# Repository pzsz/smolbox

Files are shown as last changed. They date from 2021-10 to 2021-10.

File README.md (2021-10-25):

# Smolbox thumb & pinky

[Bill of Materials](docs/BOM.md)

[Preparing Brooks board & Soldering tips](docs/brooks_prepare.md)

The Smolbox, a portable arcade controller.

* Based on the Brook Fighting Board 
* Wireless Brook Board version compatible with 
PS3&4, PC, Switch (https://www.brookaccessory.com/detail/41130595/). 
* Zero-Pi Brook Board compatible with 
PS3&2, PC, Switch (no PS4 comparability) (https://www.brookaccessory.com/detail/53169470).
* USB-C port.
* Uses hot-swapable low profile Kailh Choc Red Switches (only Choc switches can be used, full-sized switches will not work).
* Bottom plate made from 1mm brushed stainless steel or 3mm acrylic.

## Thumb version
Ultra portable fighting games controller utilising thumb finger for the jump button.
* Sized 181mm x 73mm and 17mm high (without rubber feet (1mm) and keys). Body made from 3mm acrylic.

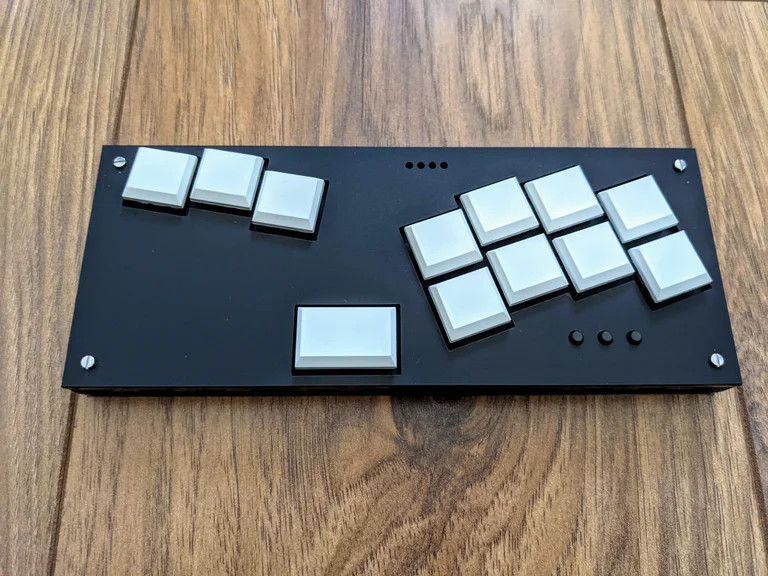
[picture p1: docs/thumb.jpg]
Smolbox Thumb


## Pinky version
Ultra portable fighting games controller utilising pinky finger for the second jump button.
* Sized 181mm x 61mm and 17mm high (without rubber feet (1mm) and keys). Body made from 3mm acrylic.

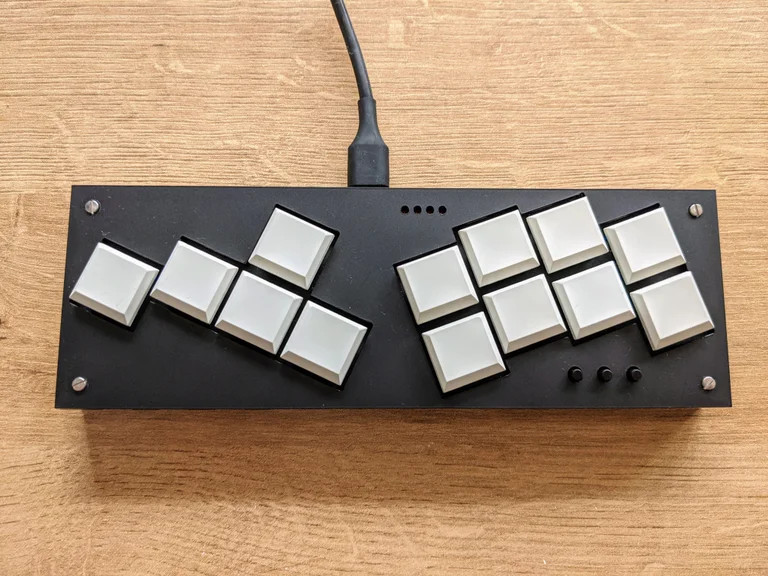
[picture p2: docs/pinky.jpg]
Smolbox Pinky


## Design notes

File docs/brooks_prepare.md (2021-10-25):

# Brooks board prepaeation

Let's prepare the Brooks Board. We have to get from here:

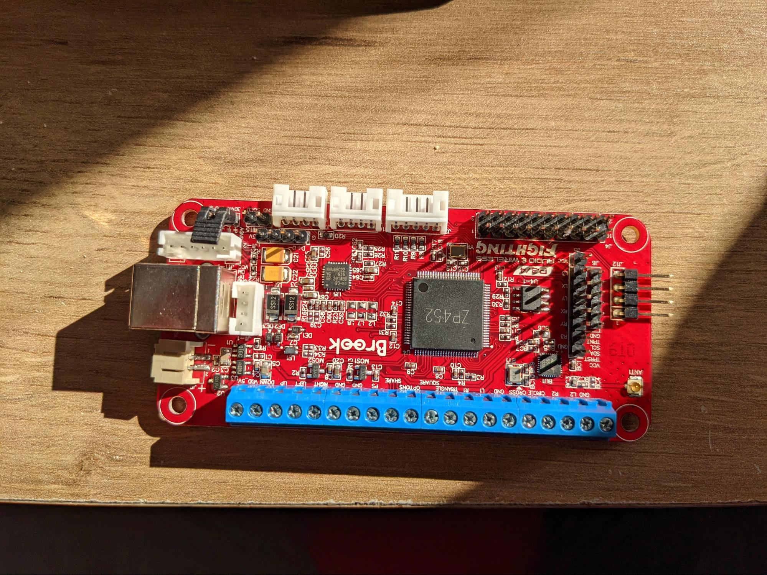
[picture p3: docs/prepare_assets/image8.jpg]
Brooks board


To this:
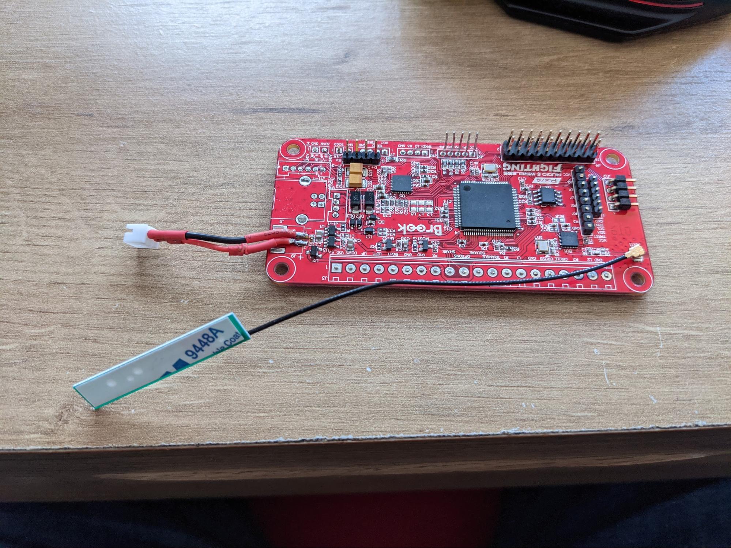
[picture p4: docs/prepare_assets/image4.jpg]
No headers


Items to be modified:
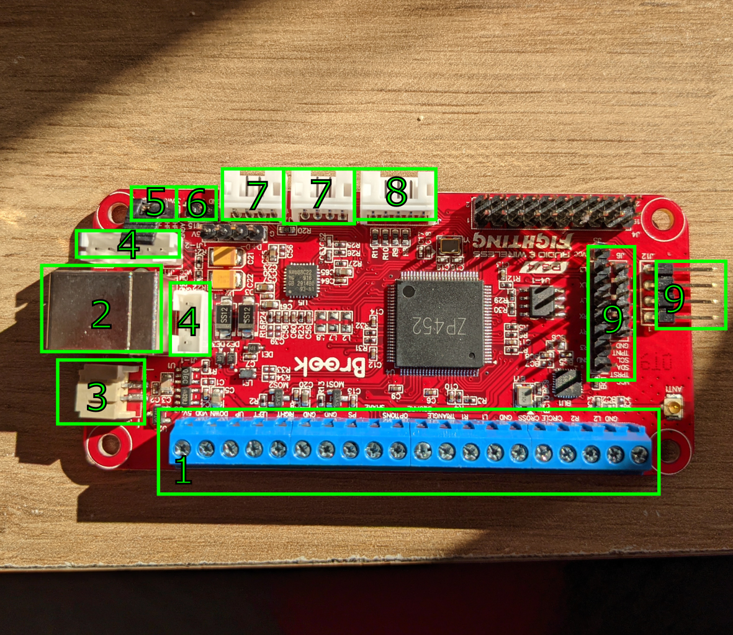
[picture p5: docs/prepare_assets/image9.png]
List of parts to be changed


1.This needs to be removed by grabbing in pliers and rocking them back and forth. Remaining pins need to be trimmed with a cutter

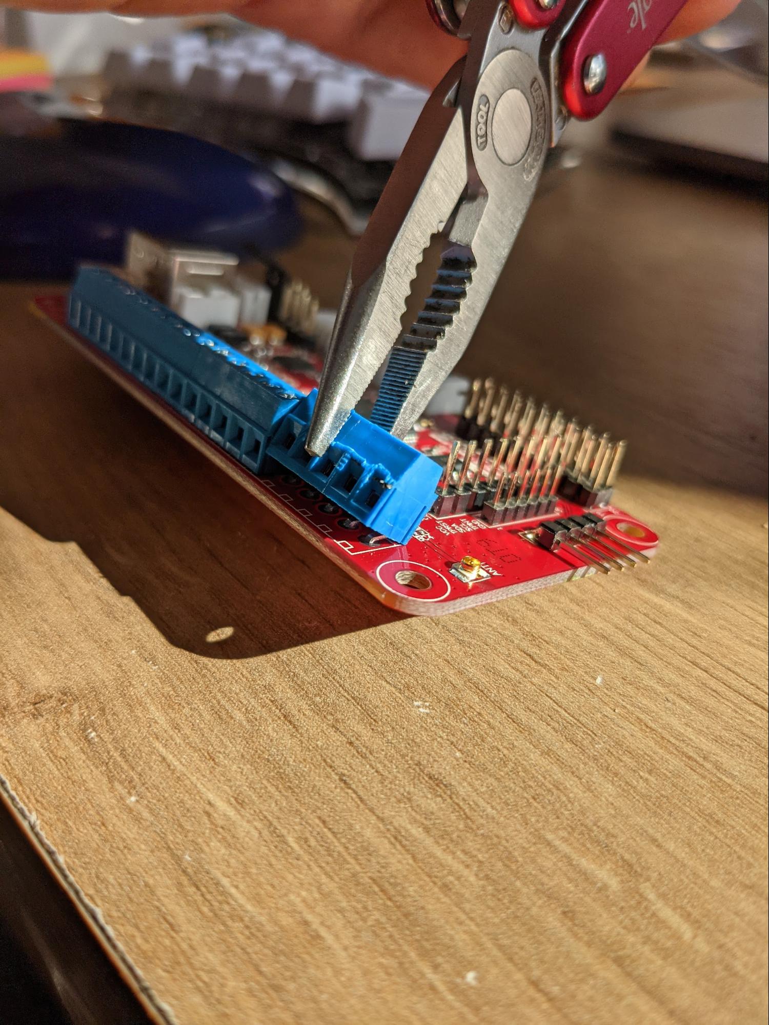
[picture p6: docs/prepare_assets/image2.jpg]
Removed usb port


2. This is the difficult one. You need to cut this into small pieces with a cutter. Be wary that this may dull your cutter if it’s too small. USB is anchored into pcb on its sides and by 4 USB pins. When you remove the side anchors, it comes off easily by rocking it back and forth.

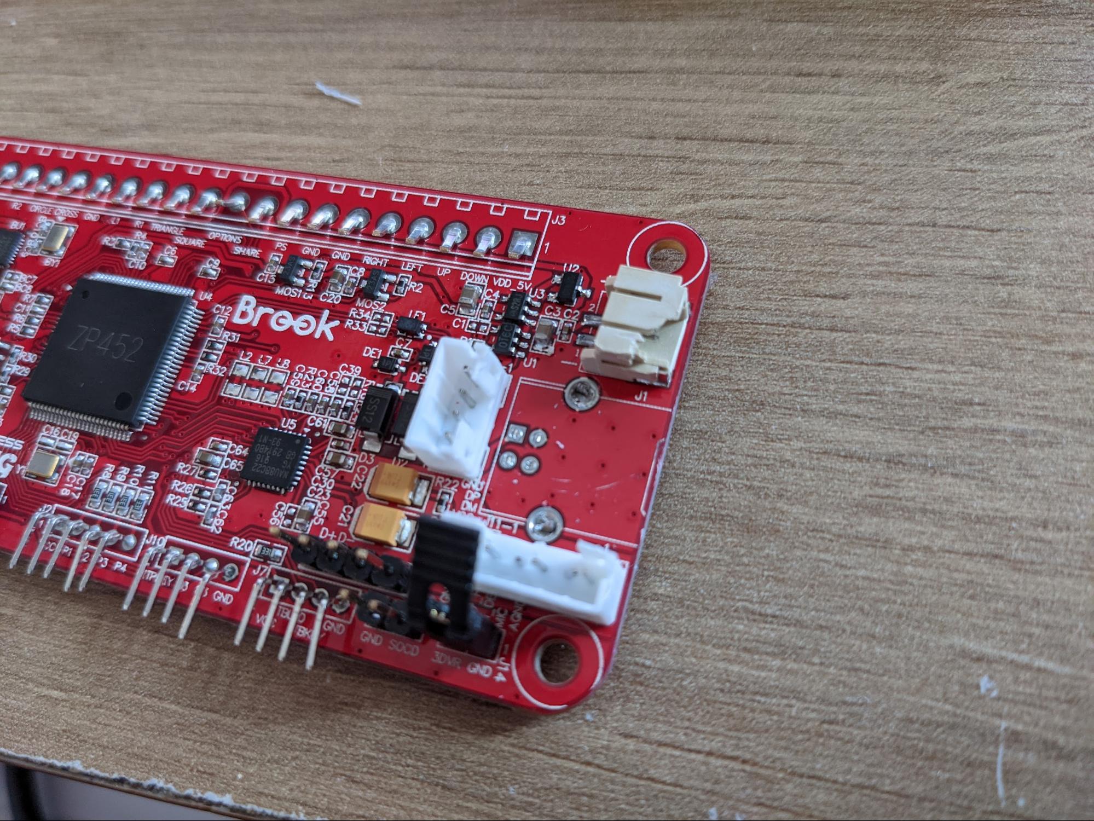
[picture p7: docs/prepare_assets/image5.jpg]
Removed port


3. Cut it away. Replace it by attached female plug on wire, or raw wires (they are single solid core, they easily go into battery JST plug).
4. Remove - cut the pins with housing. Be careful to not damage the pcb.
5. Cut down to the plastic part of the pin, solder together on the back side
6.  Cut down to the plastic part of the pin. You have to select which SCOD cleaning option you want, and either solder together on the back side, or leave alone. Personally, I use SOCD Mode 2 (left + right = nothing).
7. Remove pins and housing
8. Remove JUST the housing. Wobble it from left to right by tugging it with pliers. Then, bend them straight up.

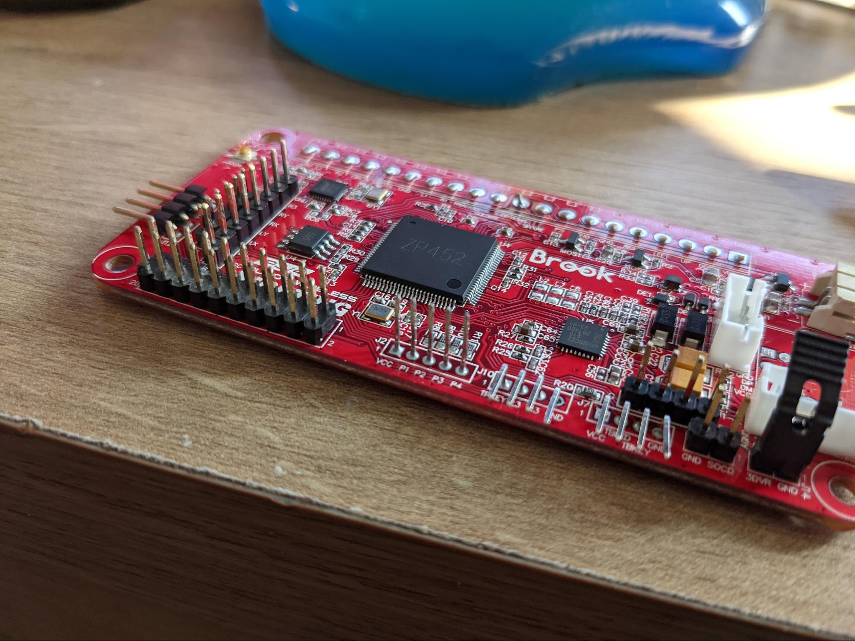
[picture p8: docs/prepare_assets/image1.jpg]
Led pins


9. Cut it down to the plastic.

# Soldering tips
* USB and resistors goes UNDER the board. The silkscreen markings for resistors are printed on the WRONG side, sorry about this.
* Top surface needs to be as flat as possible. If any solder is sticking out too much, rework to make it flat.
* Solder the brooks board as the LAST step. Be sure to connect antenna and battery connectors on the brooks, as it’s super difficult to do it afterwards.
* Solder the USBC first. Use multimeter to be sure that there are no bridges (some pins are connected on the board, consult kicad files).
* The USBC port pins may need down to the pcb board thickness - be very delicate when inserting it, to not bend any legs. Apply a ton of flux and drag-solder it with k-tip.
* Led + (longer legs) go to holes on the edge of the board. 
*Solder the leds with an acrylic board screwed to the board, to make sure they sit right.place acrylic on the table, to make sure leds are flush and not interfering with the outer acrylic plate.
* Bend legs on option switches, straighten them with pliers and solder them this with both top acrylic plates, to make sure they are well placed:

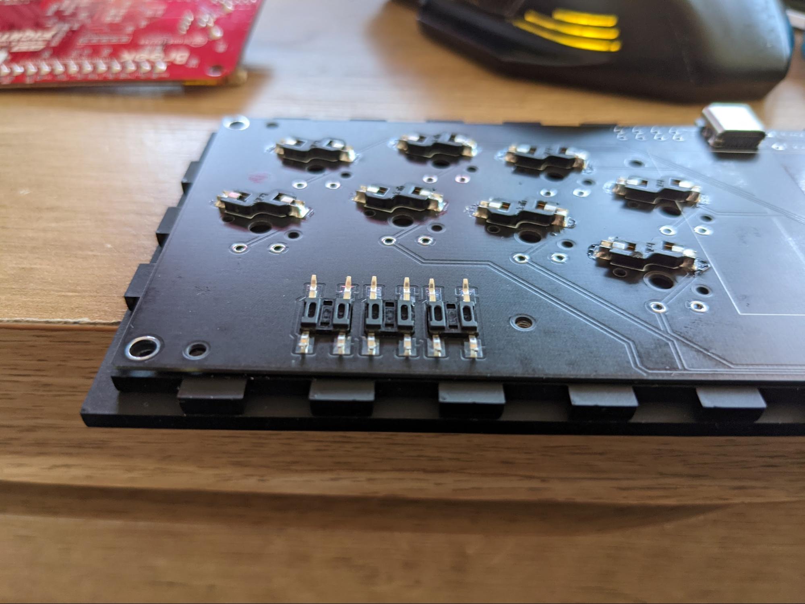
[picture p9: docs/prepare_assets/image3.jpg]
Tactile switches


# Soldering brooks board to smolbox board

* When joining Smolbox board with brooks board, connect antenna and power connector to brooks board, join them as close as possible. Verify their height against the wall panel. Cut pins flush FIRST and solder them, trying to make joins flat. Start with usb pins, so you could connect it to pc and verify that it works, in the worst case you will have to unsolder just 4 pins.
* When everything is in order, you can increase the strength of the case by glueing joins on top and side panels (but not the bottom one) inside with Tensol Acrylic glue - it melts acrylic together. But it can get very messy, screws are just fine.
* Cover the brook board with electrical tape to prevent shorting pins against the metal plate.

Tape

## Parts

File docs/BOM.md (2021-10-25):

# Bill of Materials (BOM)

| Item | Quantity | Comments|
|:---|:---|:---|
| Brooks board | 1 | Wireless, zero pi, universal. |
| Kailh choc Hot swapping socket | 13 |
| Keycaps | 13 |
| Kailh choc switches | 13 |
| 1.8mm TH leds | 4 |
| 2.4H-z antenna with ufFL connector | 1 (for wireless board) | [[Pimoroni 2.4GHz antenna]](https://shop.pimoroni.com/products/2-4ghz-mini-flexible-wifi-antenna-with-ufl-connector-100mm) works |
| 6mm Tactile switch 9mm height | 3 | [[Kitronik 9mm tactile switch]](https://kitronik.co.uk/collections/switches-sensors/products/6mm-pcb-mount-tactile-switch-95mm-height1M) |
|Screw M2 x 3mm | 5 | |
|Screw M2 x 16mm | 4 (for 1mm steel bottom plate) | |
|Screw M2  x 18mm | 4 (for 3mm acrylic bottom plate) | |,
|Battery | 1 (for wireless board) | [[Kitronik battery]](https://kitronik.co.uk/products/4652-polymer-lithium-ion-battery-1ah) |
| 5.1K TH resistors | 2 | |
| GCT USB4085-GF-A | 1 | [[USB connector]](https://www.digikey.com/en/products/detail/gct/USB4085-GF-A/9859733). The pins may need trimming with cutter if PCB is < 1.6mm |

[[Back to README]](../README.md)

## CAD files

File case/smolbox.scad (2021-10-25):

panel_width = 175;
metal_bottom_plate = true;
borked_plates = false;
thumb_variant = true;

finger_size = 7.5;

panel_height = thumb_variant ? 67 : 55;

depth = 9;

left_buffer = 0.1;
right_buffer = 0.1;
top_buffer = 0.0;
bottom_buffer = 0.0;
hor_buffers = left_buffer + right_buffer;
ver_buffers = top_buffer + bottom_buffer;

sidenotches = 4.0;
button_kerf = 0.08;
kerf = 0.1;
finger_depth = 3.1;
finger_bottom_depth = metal_bottom_plate ? 0.0 : finger_depth;
bottom_plate_depth = 0.9;

// bottom panel
brooks_offset=0.7;
brooks_w= 96.3;
brooks_h= 45.3;
brooks_holes_w=88;
brooks_holes_h=37;
hole_size = 1.4;

holes_off_w = (brooks_w-brooks_holes_w)*0.5;
holes_off_h = (brooks_h-brooks_holes_h)*0.5;

mount_off = 3.5;
board_mount_off = 10;

obutton_size= 3.6;
obutton_dist= 8;

led_dia = 1.8;
led_w = 2.5;
led_h = 3.5;

usb_x = 104.2 - 25;
usb_w = 10;
usb_h = 4.0;
pcb_h= 0.8;


switch_next = 19.05;

switch_hole = [14.0,14.0];



module finger_panel(w,h, kerf, finger_size, finger_depth,
    finger_depth_b,
w_out,h_out, add_sides) {
     wf = w / finger_size;
     wf_whole = floor(wf);
     wf_rem = wf - wf_whole;
    
     hf = h / finger_size;
     hf_whole = floor(hf);
     hf_rem = hf - hf_whole;
    
    
     union() {
	  translate([-kerf,-kerf])  square([w+2*kerf,h+2*kerf]);
        
      even = (wf_whole % 2) == 0;
      wf_removed = even ? 3 : 2;   
      offset = (wf_removed + wf_rem) * 0.5 * finger_size;
      steps = round((wf_whole-wf_removed+1) * 0.5) - (w_out ? 1 : 0);
          
	  if (steps >= 1) {
	       if (w_out) {
		    translate([-kerf,h]) square([offset+kerf*2,finger_depth+kerf]);  
		    translate([(w-offset-kerf),h]) square([offset+kerf*2,finger_depth+kerf]); 
               
		    translate([-kerf,-finger_depth_b-kerf]) square([offset+kerf*2,finger_depth+kerf]);  
		    translate([(w-offset-kerf),-finger_depth_b-kerf]) square([offset+kerf*2,finger_depth+kerf]); 
	       }
           
           
           offset2 = offset +  (w_out ? finger_size : 0);
	       for (p =[0:steps-1]) { 
			 translate([offset2+(2*p)*finger_size-kerf,h])
			 square([finger_size+kerf*2,finger_depth+kerf]);  
			 translate([offset2+(2*p)*finger_size-kerf,-finger_depth_b-kerf]) 
			 square([finger_size+kerf*2,finger_depth_b+kerf]);  
	       }
        
	  }
      
      heven = (hf_whole % 2) == 0;
      hf_removed = heven ? 3 : 2;   
      hoffset = (hf_removed + hf_rem) * 0.5 * finger_size;
      hsteps = round((hf_whole-hf_removed+1) * 0.5) - (h_out ? 1 : 0);
          
      echo("aa", h, hf_whole, hf_whole,hsteps);
	  if (hsteps >= 1) {
	       if (h_out) {
		    translate([w,-kerf-finger_depth,]) square([finger_depth+kerf,hoffset+kerf*2+ finger_depth]);  
		    translate([w, (h-hoffset-kerf)]) square([finger_depth+kerf,hoffset+kerf*2+ finger_depth]); 
               
		    translate([-finger_depth-kerf,-kerf-finger_depth,]) square([finger_depth+kerf,hoffset+kerf*2+ finger_depth]);  
		    translate([-finger_depth-kerf, (h-hoffset-kerf)]) square([finger_depth+kerf,hoffset+kerf*2+ finger_depth]); 
	       }
  
           hoffset2 = hoffset +  (h_out ? finger_size : 0);
	       for (p =[0:hsteps-1]) { 
             
			 translate([w, hoffset2+2*p*finger_size-kerf]) 
			 square([finger_depth+kerf,finger_size+kerf*2]);  
		    
			 translate([-finger_depth-kerf,hoffset2+2*p*finger_size-kerf]) 
			 square([finger_depth+kerf,finger_size+kerf*2]);  
	       }
	  } else {
   	       if (add_sides) {
    translate([-finger_depth-kerf,-kerf-finger_depth_b,]) square([finger_depth+kerf,h+kerf*2+ finger_depth_b+finger_depth]);  
               translate([w,-kerf-finger_depth_b,]) square([finger_depth+kerf,h+kerf*2+ finger_depth_b+finger_depth]);  
           }
      }
     }
}   

module thumbs(hole_size, hole_dist, thumb_mul, kerf) {    

      translate([0,0])square(hole_size-[kerf*2,kerf*2],center=true);
           
    
	  translate([hole_dist,3])  square(hole_size-[kerf*2,kerf*2],center=true);
    
	  translate([2*hole_dist,-1])square(hole_size-[kerf*2,kerf*2],center=true);

//9 for 55
	  translate([3*hole_dist+2, -hole_dist*2]) rotate([0,0,10]) translate([3,0]) square([hole_size[0]*thumb_mul, hole_size[1]]-[kerf*2,kerf*2],center=true);
        
 
}


module arrows(hole_size, hole_dist, kerf) {    

      translate([0,0])square(hole_size-[kerf*2,kerf*2],center=true);
         
    translate([hole_dist*2,hole_dist*0.5]) {
  
	    square(hole_size-[kerf*2,kerf*2],center=true);
    
	  translate([hole_dist,0])  square(hole_size-[kerf*2,kerf*2],center=true);
    
	  translate([-hole_dist,0])square(hole_size-[kerf*2,kerf*2],center=true);

	  translate([0, hole_dist]) square(hole_size-[kerf*2,kerf*2],center=true);
        
 }
}


module buttons(hole_size, hole_dist, kerf) {
     
     translate([0,0]) {
	  translate([0,0]) {
	       square(hole_size-[kerf*2,kerf*2],center=true);
    
	       translate([0, hole_dist]) square(hole_size-[kerf*2,kerf*2],center=true);
	  }
        
	  translate([hole_dist,4]) {
	  square(hole_size-[kerf*2,kerf*2],center=true);
    
	       translate([0, hole_dist]) square(hole_size-[kerf*2,kerf*2],center=true);
	  }
     
	  translate([hole_dist*2,1]) {
	       square(hole_size-[kerf*2,kerf*2],center=true);
    
	       translate([0, hole_dist]) square(hole_size-[kerf*2,kerf*2],center=true);
	  }
        
	  translate([hole_dist*3,-9]) {
	       square(hole_size-[kerf*2,kerf*2],center=true);
    
	       translate([0, hole_dist]) square(hole_size-[kerf*2,kerf*2],center=true);
          }   
     }
}

// Top panel
module top_panel(thumbs) {
    
difference() {
  
    translate([-left_buffer,-bottom_buffer])
        finger_panel(panel_width+left_buffer+right_buffer,panel_height+bottom_buffer+top_buffer, kerf, finger_size,               finger_depth, finger_depth, 
                    false, false,false);
    
    translate([usb_x, panel_height + finger_depth*0.5+kerf*1])
         square([finger_size*3.5, finger_depth+kerf*0],center=true); 
   
    if (!thumbs) {
    translate([12,30]) rotate([0,0,-25]) arrows(switch_hole, switch_next, button_kerf);
        
     translate([105,12]) rotate([0,0,20]) buttons(switch_hole, switch_next, button_kerf);
    
    } else {
            translate([17,57.5]) rotate([0,0,-10]) thumbs(switch_hole, switch_next, 1.0, button_kerf);


     translate([105,19]) rotate([0,0,20]) buttons(switch_hole, switch_next, button_kerf);
    
    }
    
    // bottom screws
    translate([0,0]) 
     translate([mount_off,mount_off]) {
            circle($fn=32,d=2-kerf*2,center=true);
     }
     
     translate([panel_width,panel_height]) 
     translate([-mount_off,-mount_off]) {
            circle($fn=32,d=2-kerf*2,center=true);
     }
     
     translate([panel_width,0]) 
     translate([-mount_off,mount_off]) {
            circle($fn=32,d=2-kerf*2,center=true);
     }
     
     translate([0,panel_height]) 
     translate([mount_off,-mount_off]) {
            circle($fn=32,d=2-kerf*2,center=true);
     }
   
    // board screws
    translate([0,0]) 
     translate([mount_off,board_mount_off]) {
            circle($fn=32,d=hole_size-kerf*2,center=true);
     }
     
     translate([panel_width,panel_height]) 
     translate([-board_mount_off,-mount_off]) {
            circle($fn=32,d=hole_size-kerf*2,center=true);
     }
     
     translate([panel_width,0]) 
     translate([-board_mount_off,mount_off]) {
            circle($fn=32,d=hole_size-kerf*2,center=true);
     }
     
     translate([0,panel_height]) 
     translate([mount_off,-board_mount_off]) {
            circle($fn=32,d=hole_size-kerf*2,center=true);
     }
     
     translate([125,10]) 
    {
            circle($fn=32,d=hole_size-kerf*2,center=true);
     }
     
     if (thumb_variant) {
         translate([100,52]) 
            circle($fn=32,d=hole_size-kerf*2,center=true);
     
     } else 
     {
       translate([66,51]) 
            circle($fn=32,d=hole_size-kerf*2,center=true);
     }
 
   
     
     // leds
    translate([90+10, panel_height-3.75]) {
       square([led_w+kerf*2,led_h-kerf*2],center=true);
      
    translate([-3.5, 0])
       square([led_w+kerf*2,led_h-kerf*2],center=true);
    
    translate([-3.5*2, 0])
       square([led_w+kerf*2,led_h-kerf*2],center=true);
            
    translate([-3.5*3, 0])
              square([led_w+kerf*2,led_h-kerf*2],center=true);
    }
    
    // buttons
    translate([panel_width - 25, 10]) {
       square([6.5,6.5],center=true);
      
    translate([-obutton_dist, 0])
       square([6.5,6.5],center=true);
    
    translate([-obutton_dist*2, 0])
       square([6.5,6.5],center=true);
    }
    
    
    //translate([usb_x, 48.8+1.5]) translate([0,0.0]) {
    //    square([usb_w,3],center=true);
    //}
}
}

// Topper
//translate([0, panel_height+10]) 
module topper(thumbs) {
difference() {
    translate([-left_buffer,-bottom_buffer])
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

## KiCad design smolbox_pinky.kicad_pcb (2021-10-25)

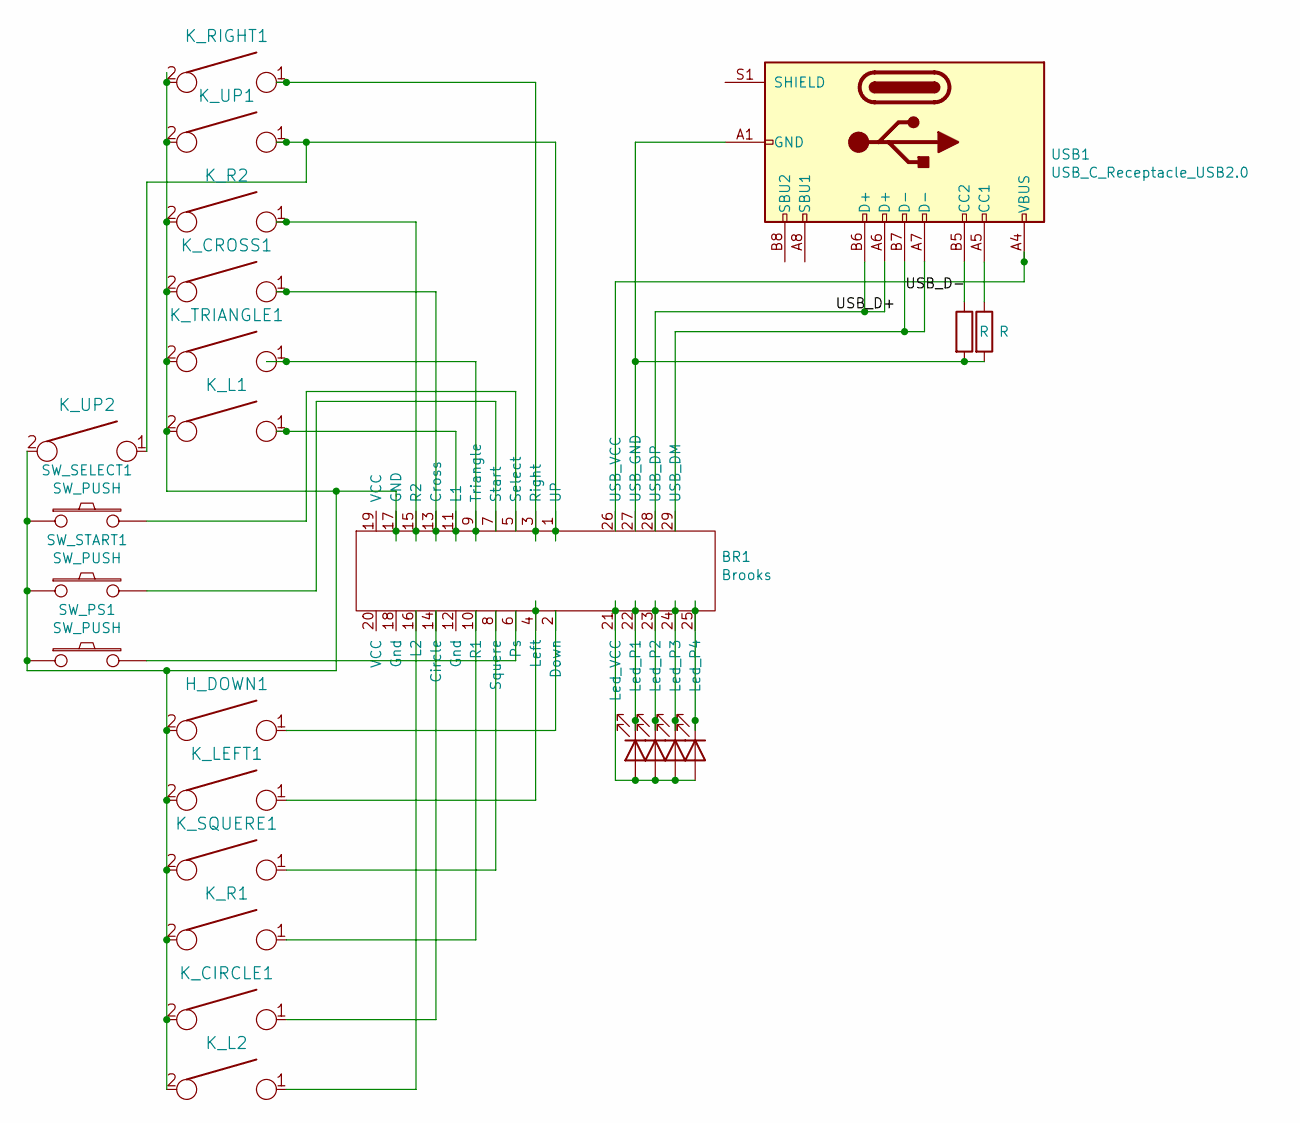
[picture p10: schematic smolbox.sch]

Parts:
BR1: Brooks
H_DOWN1: KEYSW; Kailh_socket_PG1350_optional
K_CIRCLE1: KEYSW; Kailh_socket_PG1350_optional
K_CROSS1: KEYSW; Kailh_socket_PG1350_optional
K_L1, K_L2: KEYSW; Kailh_socket_PG1350_optional
K_LEFT1: KEYSW; Kailh_socket_PG1350_optional
K_R1, K_R2: KEYSW; Kailh_socket_PG1350_optional
K_RIGHT1: KEYSW; Kailh_socket_PG1350_optional
K_SQUERE1: KEYSW; Kailh_socket_PG1350_optional
K_TRIANGLE1: KEYSW; Kailh_socket_PG1350_optional
K_UP1, K_UP2: KEYSW; Kailh_socket_PG1350_optional
L_P1, L_P2, L_P3, L_P4: LED; LED_TH
R_cc1, R_cc2: R; R_Axial_DIN0207_L6.3mm_D2.5mm_P10.16mm_Horizontal
SW_PS1: SW_PUSH; SW_PUSH_6mm_hole
SW_SELECT1: SW_PUSH; SW_PUSH_6mm_hole
SW_START1: SW_PUSH; SW_PUSH_6mm_hole
USB1: USB_C_Receptacle_USB2.0; 4085

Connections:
/USB_D+: BR1.28 (USB_DP), USB1.A6 (D+), USB1.B6 (D+)
/USB_D-: BR1.29 (USB_DM), USB1.A7 (D-), USB1.B7 (D-)
unnamed: BR1.1 (UP), K_UP1.1, K_UP2.1
unnamed: BR1.2 (Down), H_DOWN1.1
unnamed: BR1.3 (Right), K_RIGHT1.1
unnamed: BR1.4 (Left), K_LEFT1.1
unnamed: BR1.5 (Select), SW_SELECT1.2
unnamed: BR1.6 (Ps), SW_PS1.2
unnamed: BR1.7 (Start), SW_START1.2
unnamed: BR1.8 (Squere), K_SQUERE1.1
unnamed: BR1.9 (Triangle), K_TRIANGLE1.1
unnamed: BR1.10 (R1), K_R1.1
unnamed: BR1.11 (L1), K_L1.1
unnamed: BR1.13 (Cross), K_CROSS1.1
unnamed: BR1.14 (Circle), K_CIRCLE1.1
unnamed: BR1.15 (R2), K_R2.1
unnamed: BR1.16 (L2), K_L2.1
unnamed: BR1.17 (GND), H_DOWN1.2, K_CIRCLE1.2, K_CROSS1.2, K_L1.2, K_L2.2, K_LEFT1.2, K_R1.2, K_R2.2, K_RIGHT1.2, K_SQUERE1.2, K_TRIANGLE1.2, K_UP1.2, K_UP2.2, SW_PS1.1, SW_SELECT1.1, SW_START1.1
unnamed: BR1.21 (Led_VCC), L_P1.2 (A), L_P2.2 (A), L_P3.2 (A), L_P4.2 (A)
unnamed: BR1.22 (Led_P1), L_P1.1 (K)
unnamed: BR1.23 (Led_P2), L_P2.1 (K)
unnamed: BR1.24 (Led_P3), L_P3.1 (K)
unnamed: BR1.25 (Led_P4), L_P4.1 (K)
unnamed: BR1.26 (USB_VCC), USB1.A4 (VBUS), USB1.A9 (VBUS), USB1.B4 (VBUS), USB1.B9 (VBUS)
unnamed: BR1.27 (USB_GND), R_cc1.2, R_cc2.2, USB1.A1 (GND), USB1.A12 (GND), USB1.B1 (GND), USB1.B12 (GND)
unnamed: R_cc1.1, USB1.A5 (CC1)
unnamed: R_cc2.1, USB1.B5 (CC2)

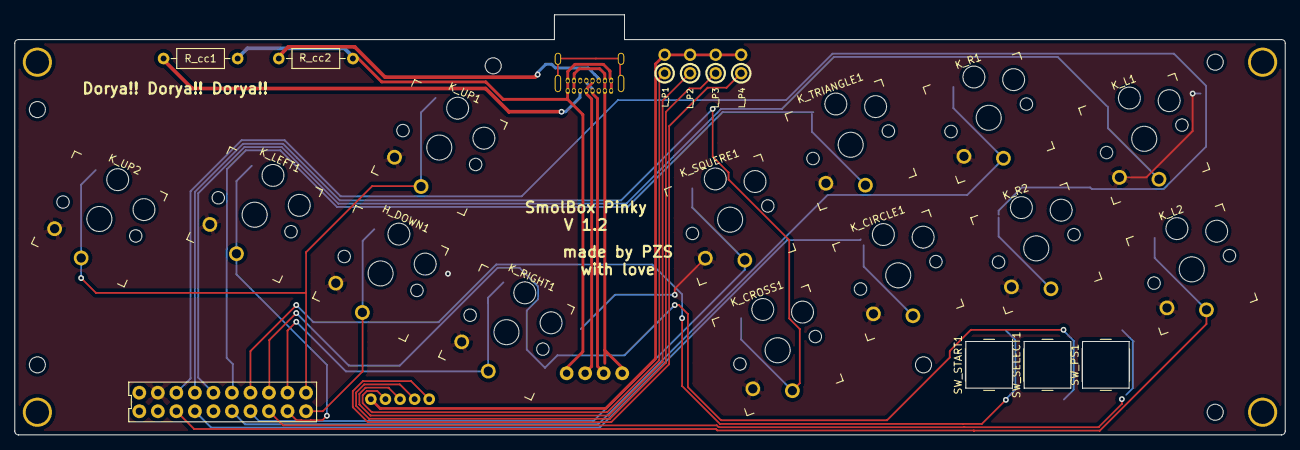
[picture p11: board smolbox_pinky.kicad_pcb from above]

Board: 2 copper layers, 174.2 x 57.6 mm, 28 parts (1 on the bottom side), 27 nets.

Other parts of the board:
HOLE_M3, HOLE_M3#2, HOLE_M3#3, HOLE_M3#4: H1; HOLE_M3

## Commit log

2021-10-25 Add kicad_lib_tmk
2021-10-25 Initial version
    [smolbox.sch, smolbox_pinky.kicad_pcb, smolbox_thumb.kicad_pcb]
2021-10-25 Case scad model
    [smolbox.scad]
2021-10-25 BOM docs
2021-10-25 BOM docs updated with USBC port
2021-10-25 Preparing brooks board
